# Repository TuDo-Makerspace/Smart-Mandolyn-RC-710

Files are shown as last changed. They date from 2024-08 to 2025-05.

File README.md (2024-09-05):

# Hacking a Mandolyn RC-710 RF Remote Power Socket <!-- omit in toc -->

<p align="center">
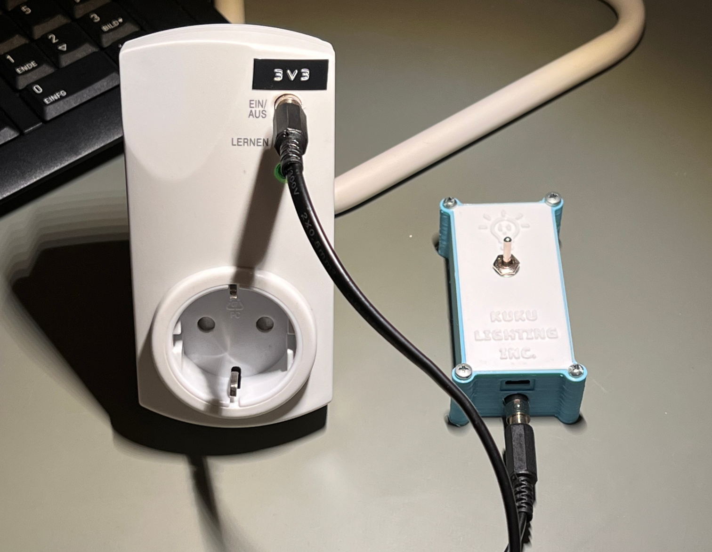
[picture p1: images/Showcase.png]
Showcase
  
</p>

In this project, I hacked a budget-friendly Mandolyn RC-710 RF remote power socket to make it controllable via WiFi—in other words, to turn it into a "smart" power socket. Along the way, I reverse-engineered the RC-710's schematics, modified the PCB to safely allow external toggling of the built-in relay, and developed an ESP8266-based board that controls the relay wirelessly via TCP.

## Table of Contents <!-- omit in toc -->

- [Disclaimer](#disclaimer)
- [Motivation](#motivation)
  - [1. The primary motivation: Laziness](#1-the-primary-motivation-laziness)
  - [2. Why Not Just Buy a WiFi Smart Plug?](#2-why-not-just-buy-a-wifi-smart-plug)
  - [3. Why not build something from scratch?](#3-why-not-build-something-from-scratch)
  - [4. Why the Mandolyn RC-710?](#4-why-the-mandolyn-rc-710)
- [About the Mandolyn RC-710](#about-the-mandolyn-rc-710)
    - [The power socket](#the-power-socket)
    - [The remote](#the-remote)
    - [Availability](#availability)
- [Reverse Engineering the RC-710](#reverse-engineering-the-rc-710)
  - [Opening the RC-710](#opening-the-rc-710)
  - [Reverse Engineering the Schematic](#reverse-engineering-the-schematic)
  - [The circuit](#the-circuit)
    - [Power Supply](#power-supply)
    - [Relay](#relay)
    - [RF Receiver](#rf-receiver)
    - [The blob IC](#the-blob-ic)
- [Modifying the RC-710](#modifying-the-rc-710)
  - [Safety First](#safety-first)
  - [Hijacking the PCB](#hijacking-the-pcb)
- [WiFi Board](#wifi-board)
  - [Design](#design)
  - [Firmware](#firmware)
- [Mobile App](#mobile-app)
- [Conclusion](#conclusion)

## Disclaimer

<p align="center">
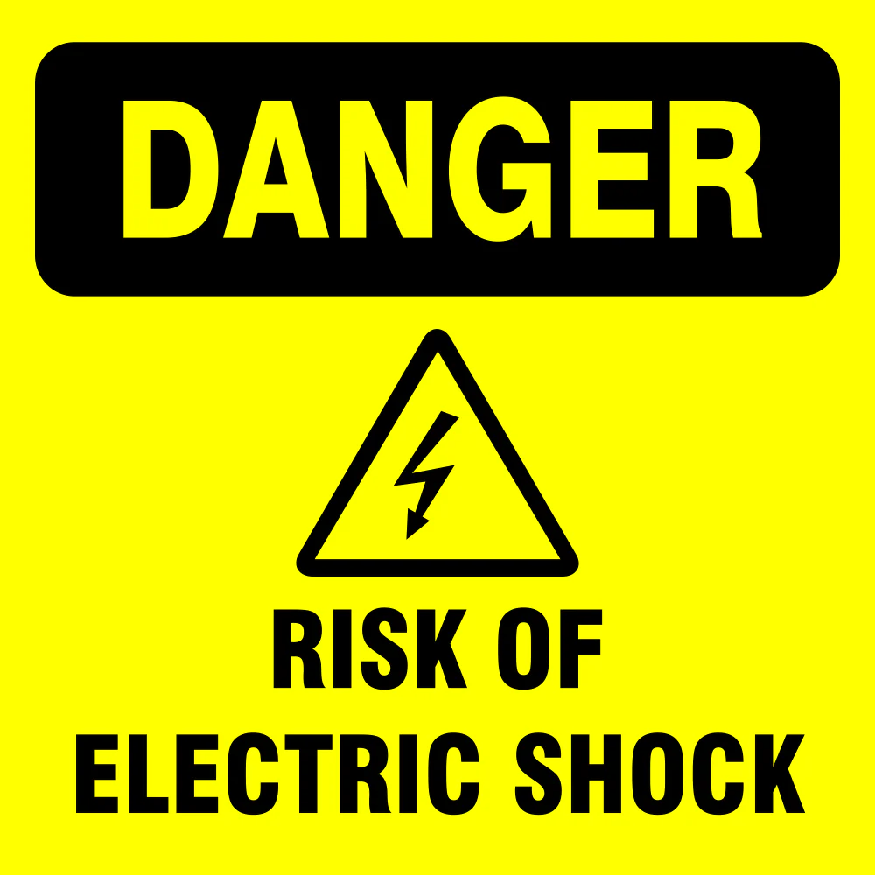
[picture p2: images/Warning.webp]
Warning
  
</p>

The RC-710 is powered by an unisolated power supply. This means that when the device is powered from mains as intended, any low voltages measured on the board will still be at a potentially lethal voltage relative to earth ground. To stress this: Simply touching a pin labeled "0V GND" on the schematic will apply a dangerous voltage (at worst 325V DC) across your body! As we’ll explore, a 24V DC power supply can be connected to the board instead of mains for testing purposes, eliminating the risk of electric shock. However, it should be crystal clear: **Do not mess with this device unless you know exactly what you’re doing! I am not responsible for any damage or injury caused by attempting to replicate this project.** Even with my experience, I am still endangering myself by working on this device.

## Motivation

### 1. The primary motivation: Laziness

We have a 230V powered IKEA lamp in our apartment. Sometimes, I’m just too lazy to get up and turn it off… Seriously, that’s the whole reason.

### 2. Why Not Just Buy a WiFi Smart Plug?

I could’ve bought a 10€ WiFi "smart plug," but I’m not thrilled with what’s out there. For one, I still like having a physical button or switch within easy reach to control the lamp. Most smart plugs I found only have a button directly on the plug. This can lead to awkward situations where you try to use the lamp’s built-in switch, but it doesn’t turn on because the smart plug is off. Having a separate, easily reachable button should avoid this issue.

The second reason is that I’m not a fan of the apps that come with these plugs. They often offer way more than I need. As you’ll see later, I’ve built my own app for this project that just shows a tappable photo of the lamp to toggle it on and off. Simple, straightforward, and tailored to my needs. Some might even call it an enterprise solution :)

### 3. Why not build something from scratch?

Hacking an existing remote power socket offers the advantage of a ready-made enclosure and a PCB that’s (hopefully) designed to handle the high voltages safely.

### 4. Why the Mandolyn RC-710?

We had a few of these lying around the lab, collecting dust. I figured it was time to give them a new purpose.

## About the Mandolyn RC-710

The RC-710 is a remote-controlled power socket that toggles on and off using a 433MHz RF remote, which comes bundled with the socket.

#### The power socket

The socket itself has two buttons: one to manually toggle the power on and off, and another to "learn" a new remote code. It also has a green LED that lights up when the socket is on.

<p align="center">
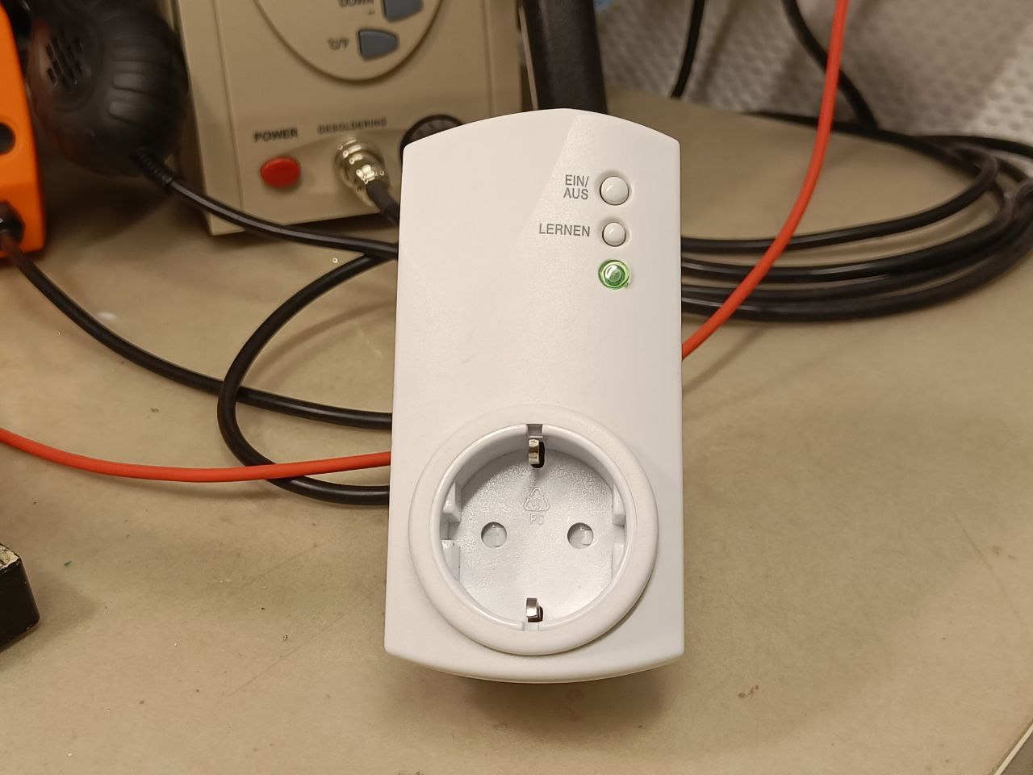
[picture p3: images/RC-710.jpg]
RC-710
  
</p>

#### The remote

The RF remote operates on up to four channels, each with its own unique 433MHz code. Each channel has an ON and an OFF button, allowing you to control multiple sockets independently. It also features two "Xanax-shaped" buttons: one to toggle all channels on or off simultaneously, and another to dim or brighten the connected device. The dimming function is not supported by the RC-710 and is intended for another model.

Since this project discards the RF remote in favor of WiFi control, we won’t be delving into the remote any further.

<p align="center">
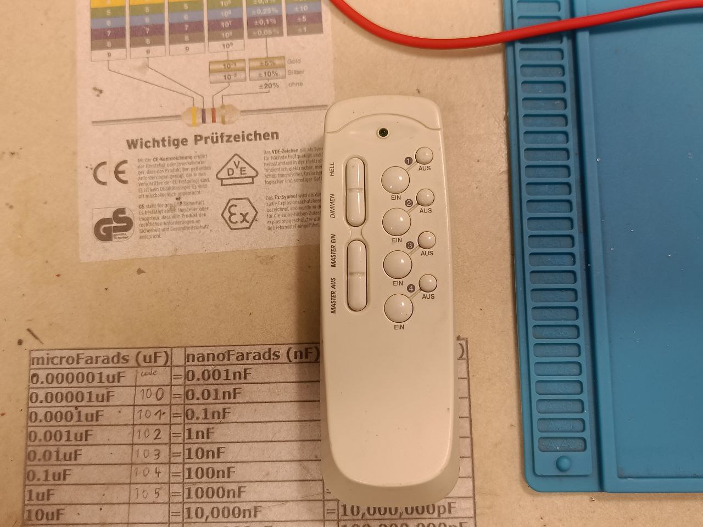
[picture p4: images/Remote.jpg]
Remote
  
</p>

#### Availability

Not much information is available about these things. They’re sold under various brand names (e.g., Voltcraft Cost Control 3000), but the internals remain the same. I also believe they were once sold at Lidl.

## Reverse Engineering the RC-710

### Opening the RC-710

Opening up the RC-710 is pretty straightforward. Start by removing the six screws on the back, and the two halves of the enclosure will come apart easily. You might also need to press in the AC plug to release it from the enclosure.

<p align="center">
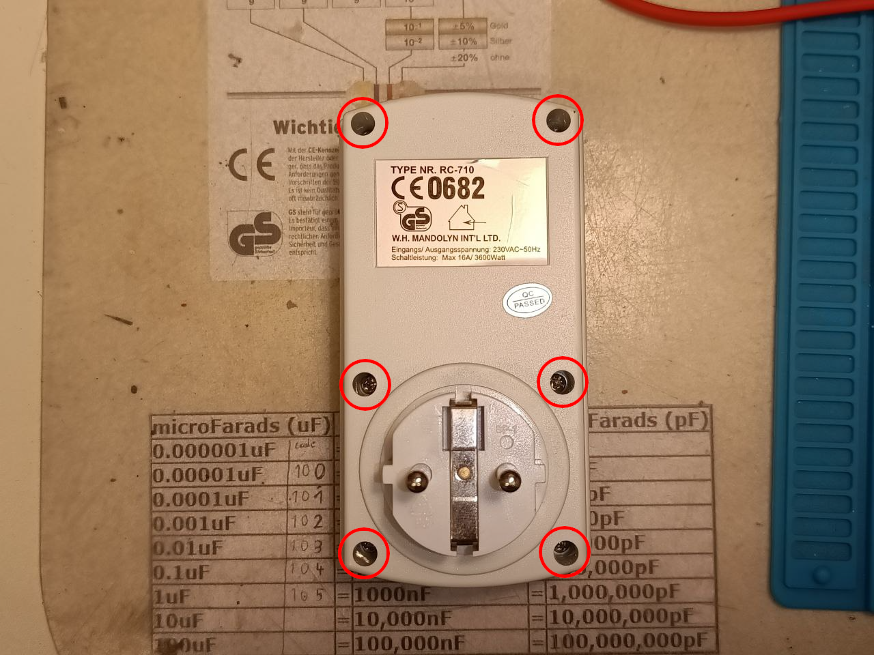
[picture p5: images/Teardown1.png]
Screws Outside
  
</p>

Once inside, you'll see the top side of a simple one-sided PCB. The PCB is secured with four smaller screws. After removing these, you can lift the PCB out of the enclosure.

<p align="center">
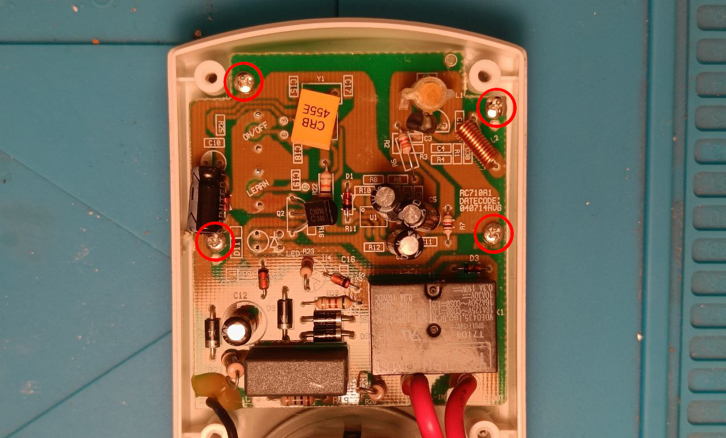
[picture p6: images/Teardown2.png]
Screws PCB
  
</p>

### Reverse Engineering the Schematic

I started by taking photos of both the top and bottom sides of the PCB, then overlapping them in GIMP. After adjusting the images, I managed to get the traces of both layers almost perfectly aligned. This setup allowed me to quickly toggle between the two layers by simply showing or hiding the top layer.

<p align="center">
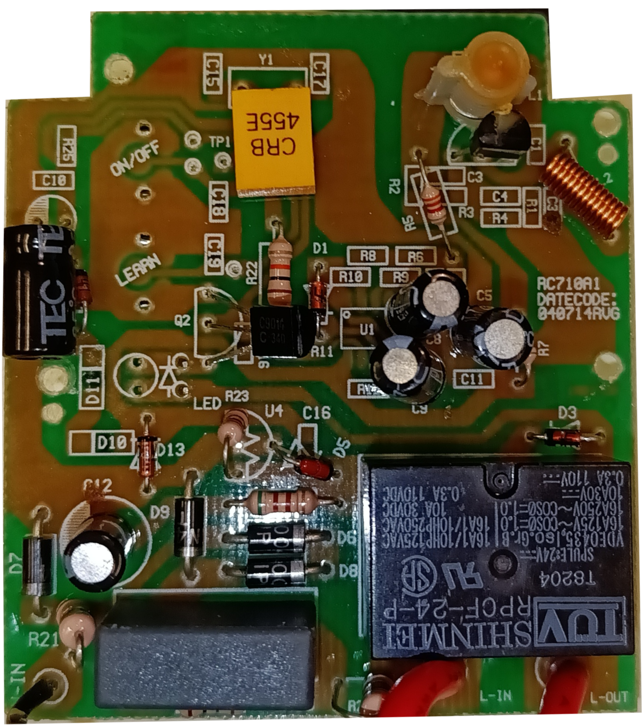
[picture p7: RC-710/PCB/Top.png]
PCB Top
  
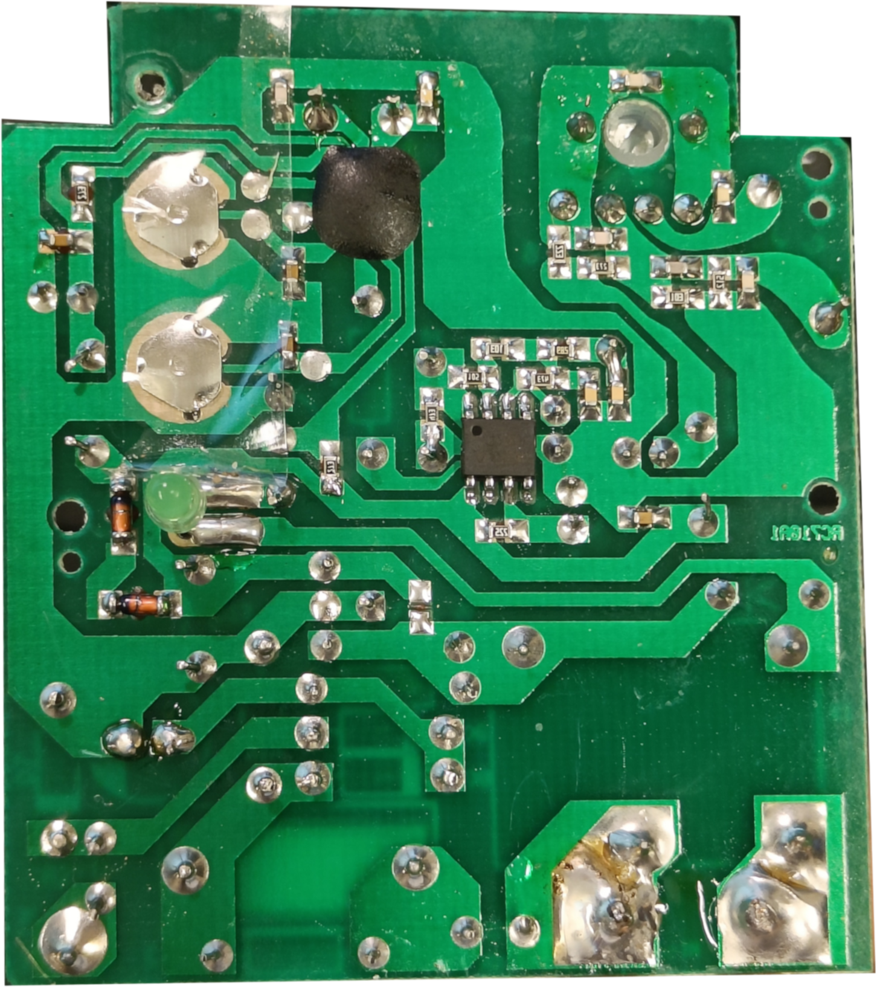
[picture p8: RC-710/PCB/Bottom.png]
PCB Bottom
  
</p>

On a second screen, I opened up KiCAD to create a schematic. I began by adding symbols for all the components. From there, I started connecting the symbols according to the PCB's traces. When the images from GIMP didn’t provide enough detail, I used a multimeter to verify connections between components. After getting everything laid out, I was left with a rather messy schematic. The final step was to clean it up and make it more readable.

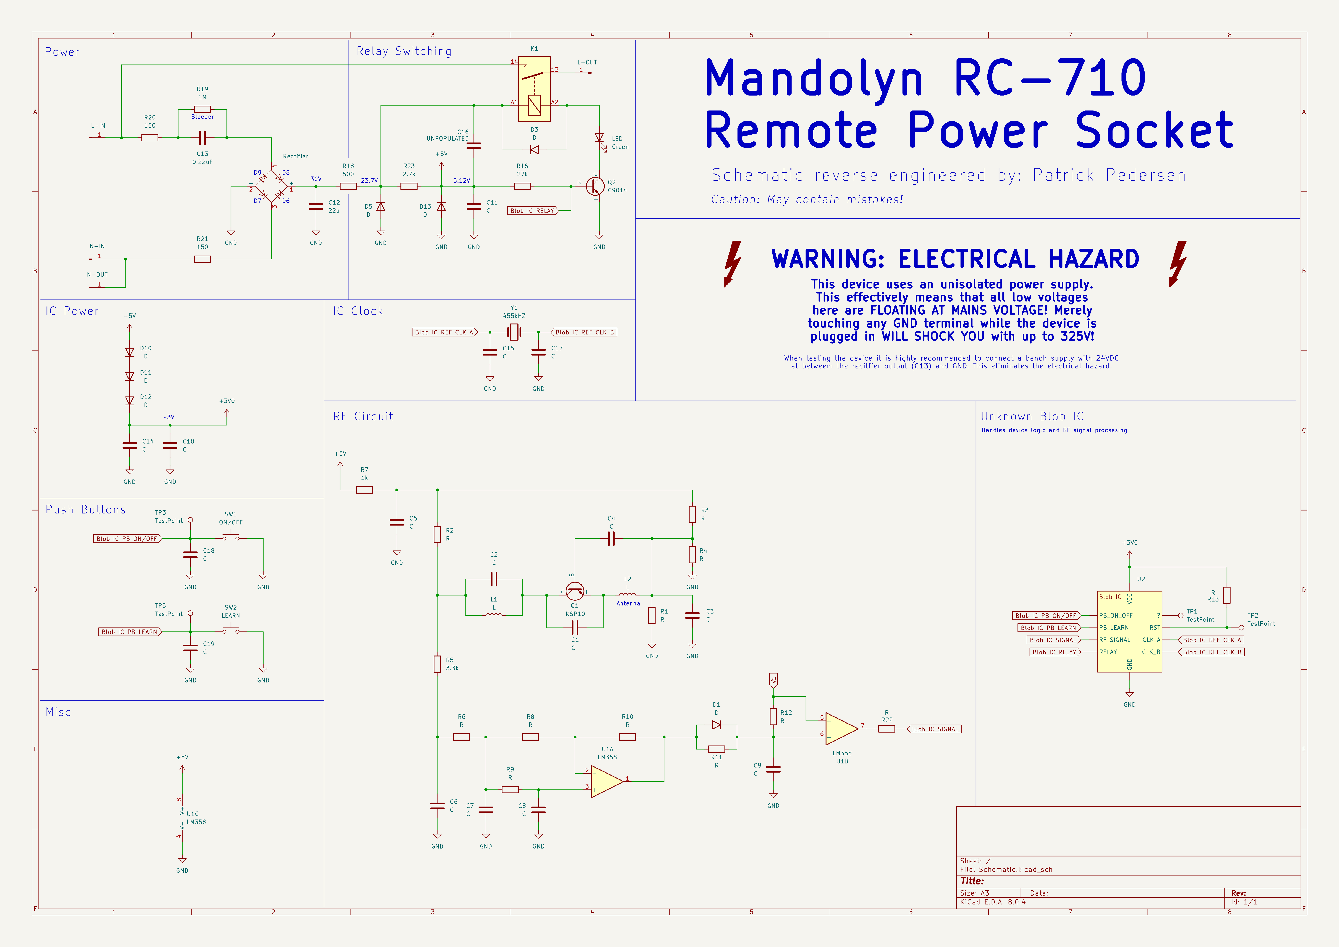
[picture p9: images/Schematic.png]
Schematic


### The circuit

All-in-all, the circuit can be summarized into 3 main parts: the power supply, the relay, and the RF receiver. Most of the device's functionality is handled by a mysterious blob IC.

#### Power Supply

The power supply circuit is as simple as it gets. The AC mains voltage is first rectified by a full-wave bridge rectifier. This rectified voltage is then regulated down to 24V DC using a Zener diode and a smoothing capacitor. The 24V DC is used to power the relay. Finally, the 24V DC is further regulated down to 5V DC, again using a Zener diode and a smoothing capacitor, to supply power to the rest of the circuitry.

<p align="center">
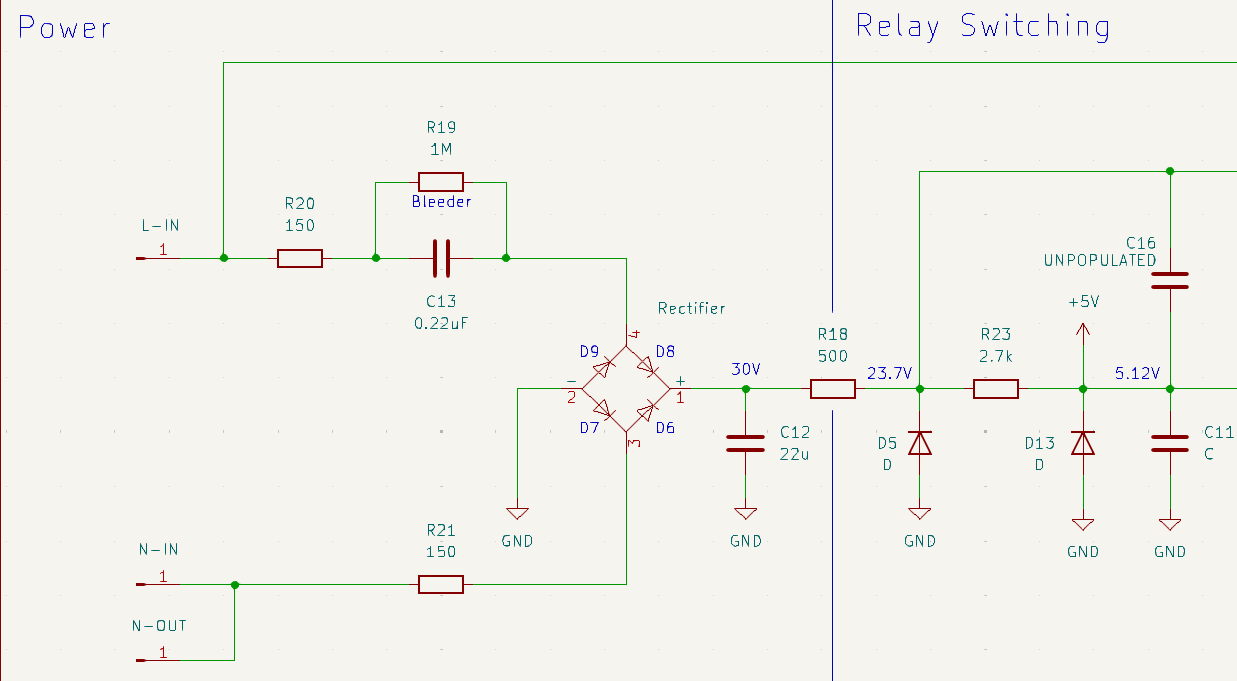
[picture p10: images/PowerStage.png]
Power Supply
  
</p>

#### Relay

The relay's job is to switch the "live" line. To activate the relay, transistor Q2 is employed. Applying a 5V signal to the base of transistor Q2 activates it, allowing current to flow through the relay coil and closing the relay circuit. This also turns on the indicator LED, as it is connected in series with the relay coil. When the relay is activated, it closes the "live" line.

The mysterious blob IC is responsible for controlling the relay by either pulling the transistor's base low or leaving it floating at 5V. When the device powers up, the IC's pin defaults to a floating state, meaning the relay circuit is closed and the device is enabled.

<p align="center">
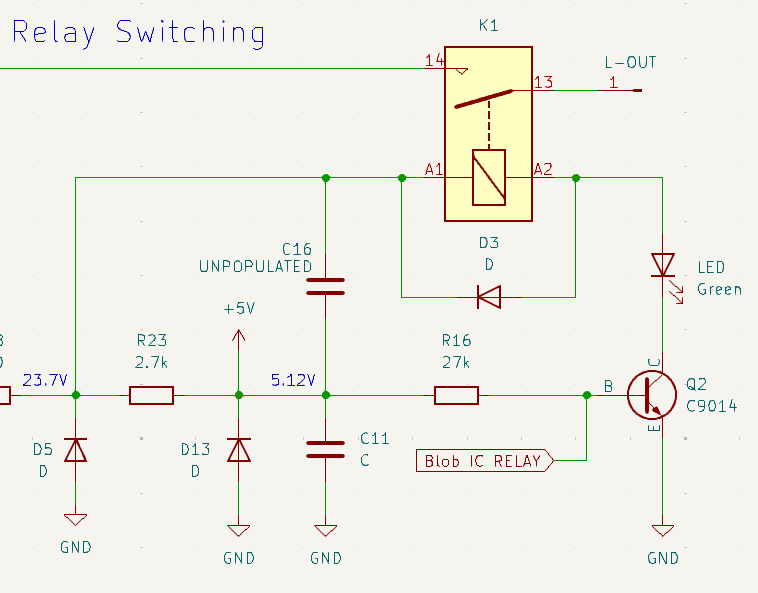
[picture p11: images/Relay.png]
Relay
  
</p>

#### RF Receiver

The RF receiver is made up of a network of capacitors, inductors, and transistors. I haven’t delved too deeply into this section of the circuit, as it’s quite complex and not directly relevant to my objective. From what I can gather, the RF signal is amplified and then converted into a PWM signal by the LM358 Op-Amp (U1). It seems that the actual demodulation and decoding of the signal is entirely handled by the mysterious blob IC.

<p align="center">
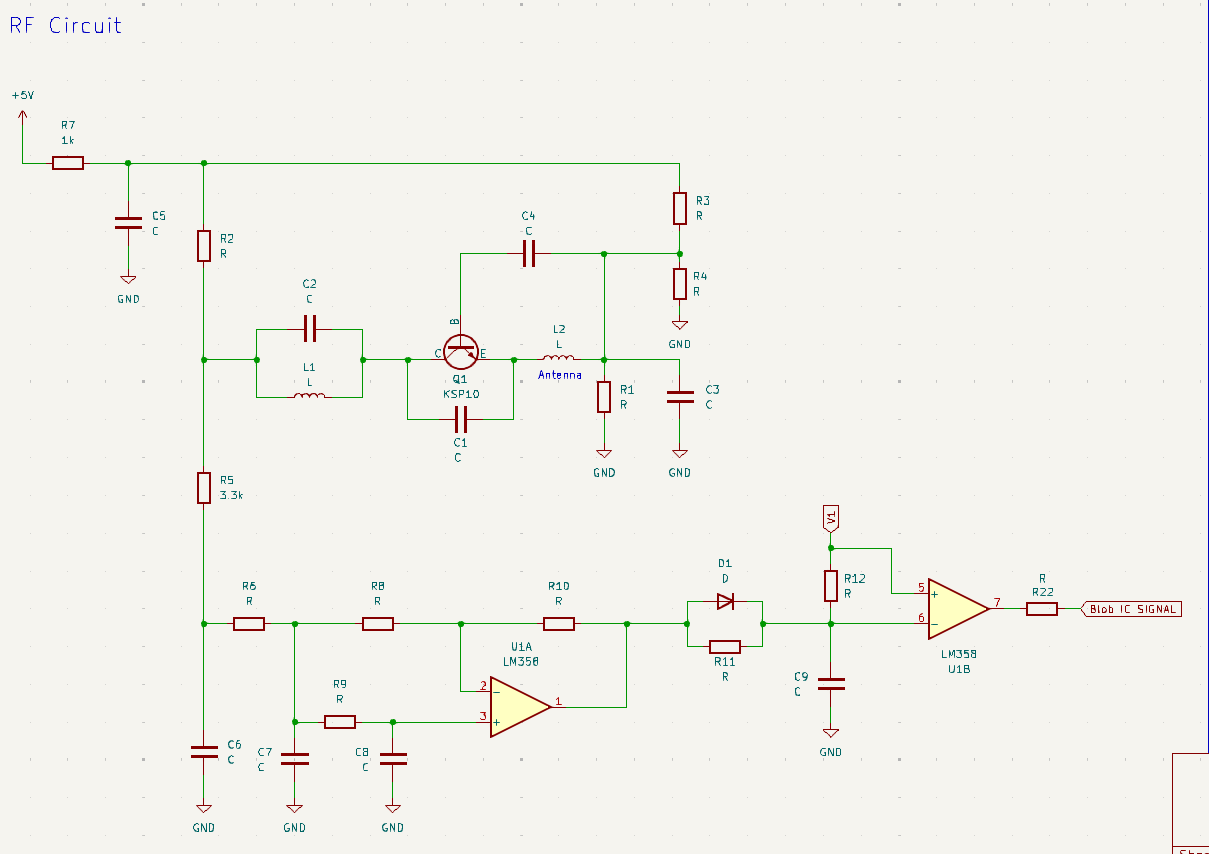
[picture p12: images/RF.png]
RF Receiver
  
</p>

#### The blob IC

The mysterious blob IC serves as the brains of the device. It is powered by approx. 3V (regulated down from the 5V supply using diodes) and manages the "LEARN" and "ON/OFF" push-buttons, decodes and "learns" RF signals, and ultimately controls the relay by switching the transistor Q2.

<p align="center">
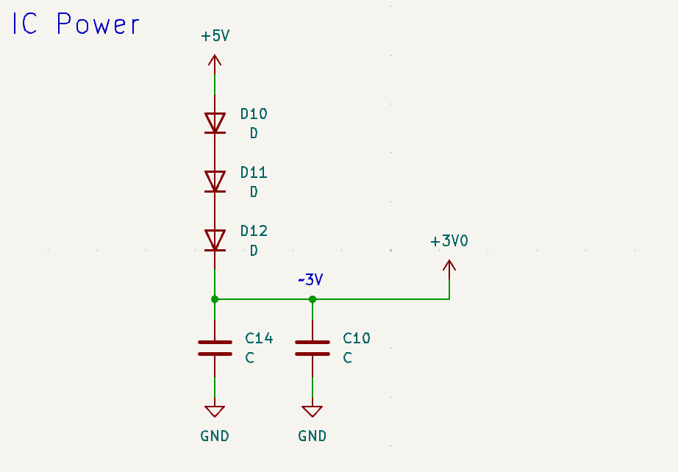
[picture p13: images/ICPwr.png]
Blob IC Power
  
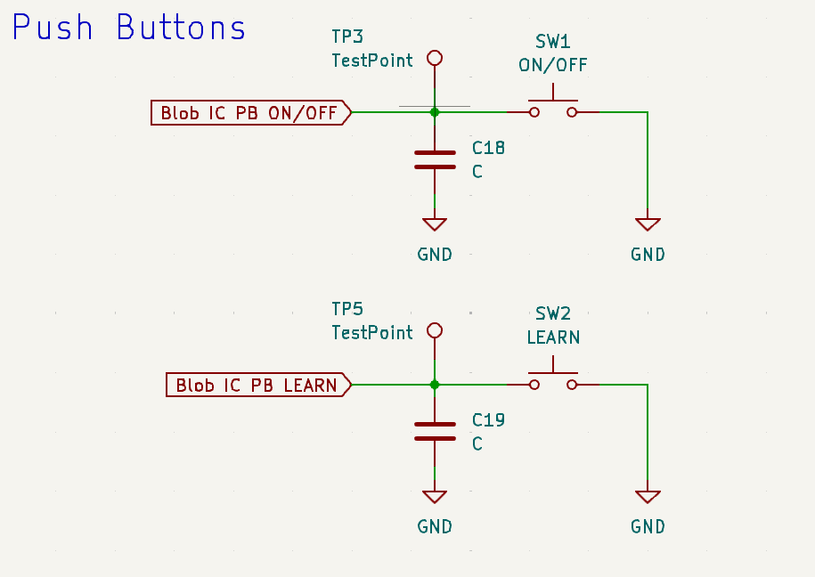
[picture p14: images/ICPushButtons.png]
Blob IC Push Buttons
  
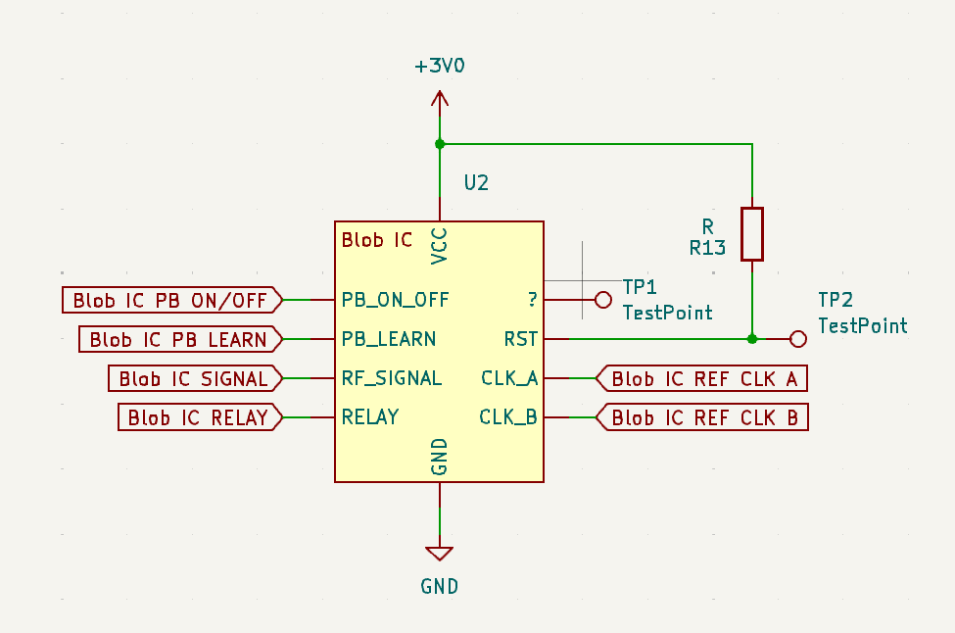
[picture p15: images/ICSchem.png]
Blob IC Schematic
  
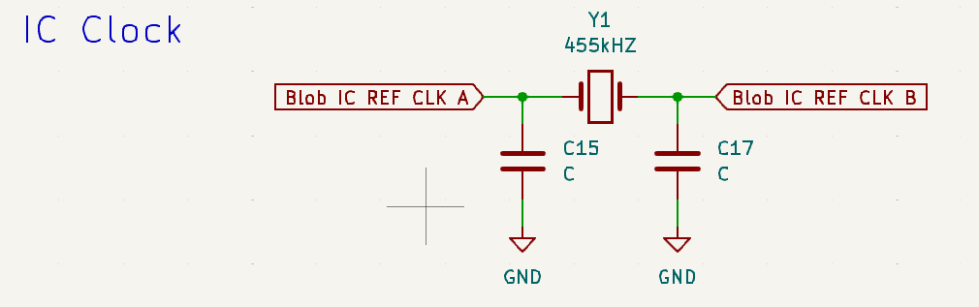
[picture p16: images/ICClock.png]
Blob IC Clock
  
</p>

<p align="center">
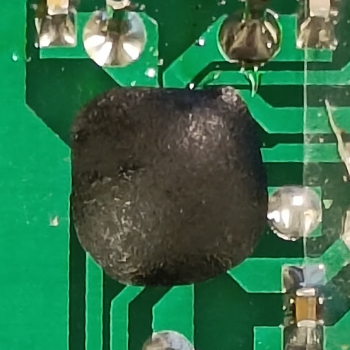
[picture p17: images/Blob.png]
Blob IC
  
</p>

## Modifying the RC-710

### Safety First

Before applying any modifications to the RC-710, I wanted to ensure that I could safely work on the device without the risk of electric shock.To achieve this, I decided to power the device using a 24V DC power supply instead of mains by attaching the postive lead to the positive side of C12 and the negative lead to GND.

<p align="center">
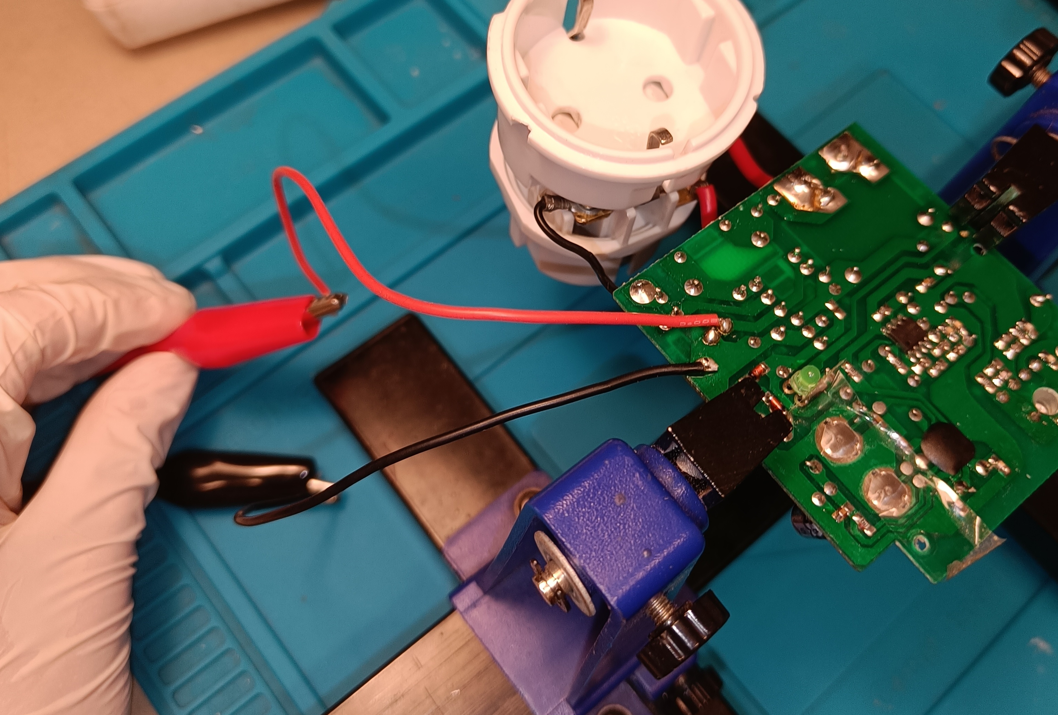
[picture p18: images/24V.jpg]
24V DC Power Supply
  
</p>

A 5V supply can theoretically also be used to power the device, but the relay will no longer be able to switch due to the insufficiently strong magnetic field.

### Hijacking the PCB

I set some straightforward rules and requirements for the project:

- The relay should be controllable via an external signal:
  - An ON signal should close the relay.
  - An OFF signal should open the relay.
- The state of the relay must be predictable:
  - The device's internal functions should not interfere with the external signal.
- The device's internal functionality does not need to be preserved.
- The external signal must be electrically isolated from the device.

To hijack the device, the first step was to find a simple way to disable the blob IC. That way I didn't have to worry about the device's internal functions interfering with the external signal. This was easily achieved by depraiving the blob IC of its power by desoldering diode D12. Later I discovered that R22 also needed to be removed, as a high state on the OP-AMP’s output was feeding blob with power to pull down the base of the relay driver transistor Q2.

<p align="center">
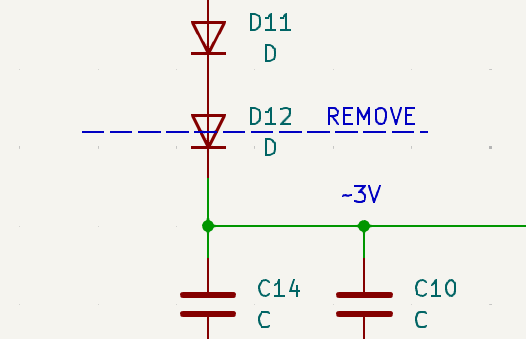
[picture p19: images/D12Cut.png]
D12 Removed
  
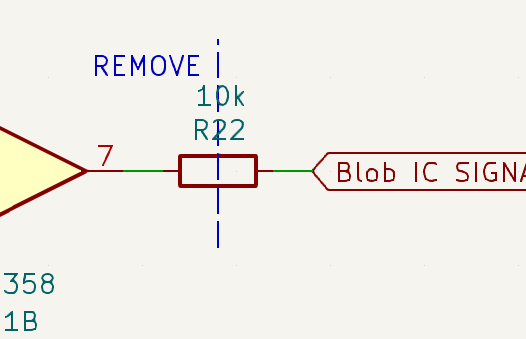
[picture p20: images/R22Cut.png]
R22 Removed
  
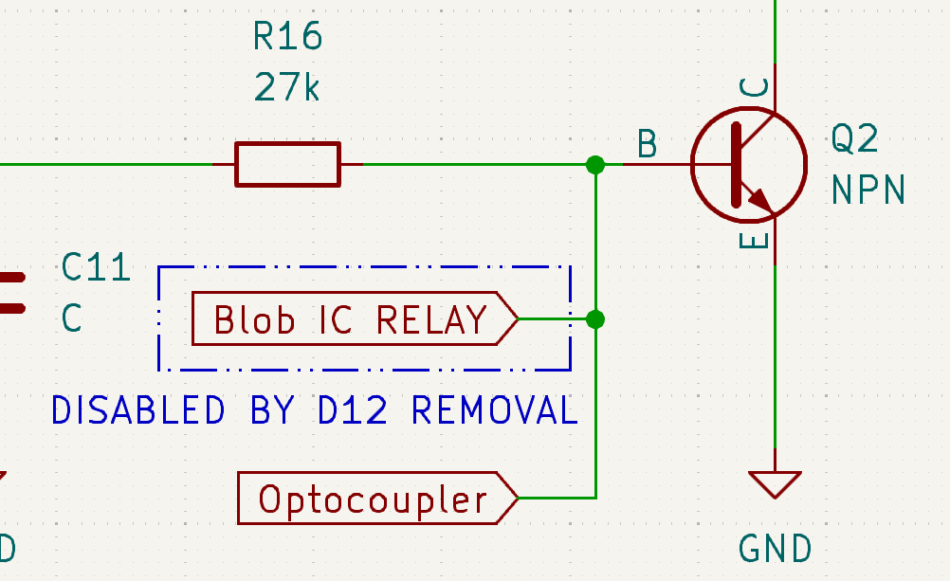
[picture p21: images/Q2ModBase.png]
Blob IC Disabled
  
</p>

The next step was to enable external control of the relay transistor's base. I wanted to add a 2-pin connector to the device's case that could be used to control the relay. For safety, this connector needed to be electrically isolated from the rest of the device. To achieve this, I used a 4N25 optocoupler, which we had plenty of in the lab, and a 3.5mm headphone jack as the external connector.

The 4N25 optocoupler contains an NPN phototransistor. By connecting the phototransistor to the base of Q2, the base would be pulled down when the phototransistor is activated (disabling the relay) and left floating when it's off (enabling the relay). I chose a headphone jack as the connector because it’s a widely available standard, and long audio cables are inexpensive or easy to make.

To protect the "low voltage" side of the optocoupler, I also added a 220 Ohm current-limiting resistor. While the use of a headphone jack might tempt someone to connect an audio source to it, the high output impedance of audio devices, combined with the 220 Ohm resistor, should keep the optocoupler safe. In the worst-case scenario, it would just cause the relay to toggle rapidly.

<p align="center">
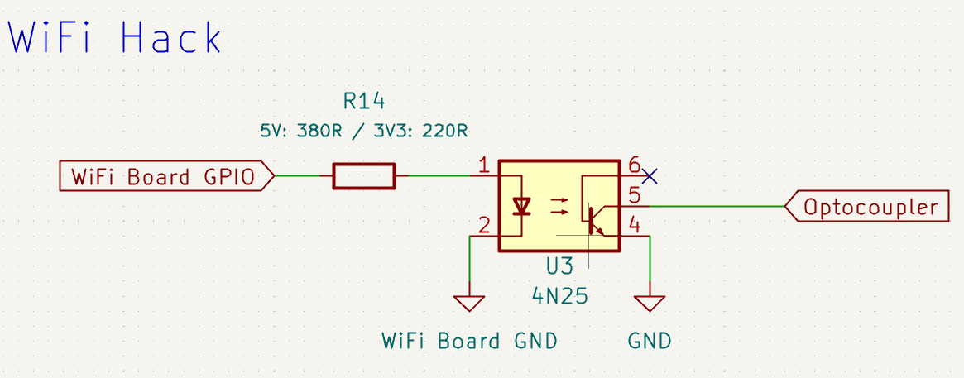
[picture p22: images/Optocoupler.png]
Optocoupler
 
</p>

After soldering the optocoupler to the PCB and the headphone jack, I secured the optocoupler inside the case with glue. The headphone jack was glued into the hole previously used for the "ON/OFF" push-button. I also used a JST XH 2-pin connector between the optocoupler and the PCB for the "hot" connection. This allows the PCB to still be easily removed from the case. For added safety, I applied plenty of electrical tape to any areas that could potentially expose the exterior to the device's mains voltage, even remotely.

<p align="center">
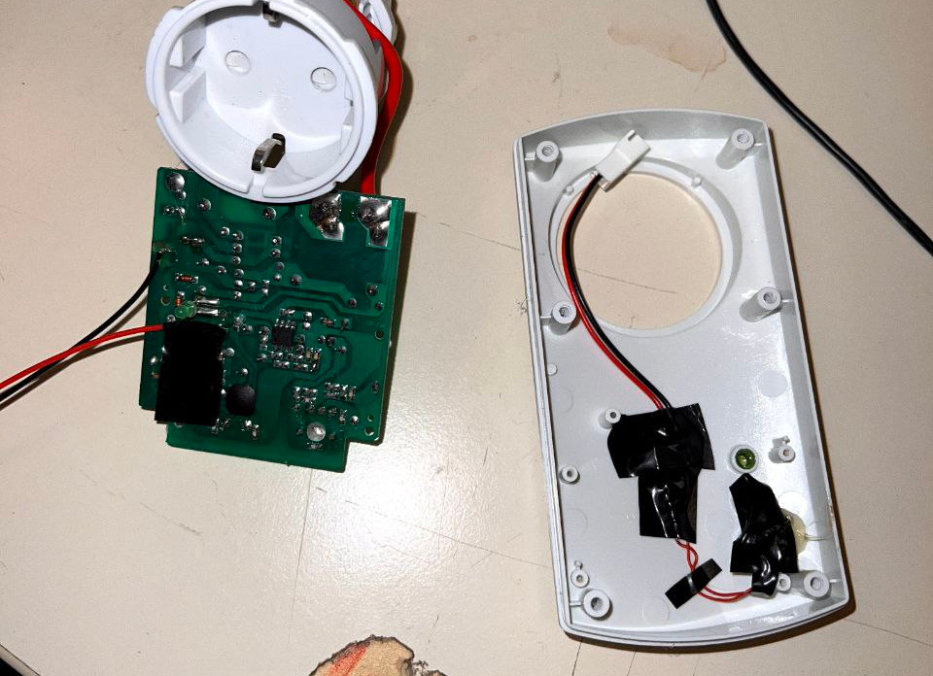
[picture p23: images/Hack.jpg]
Inside
  
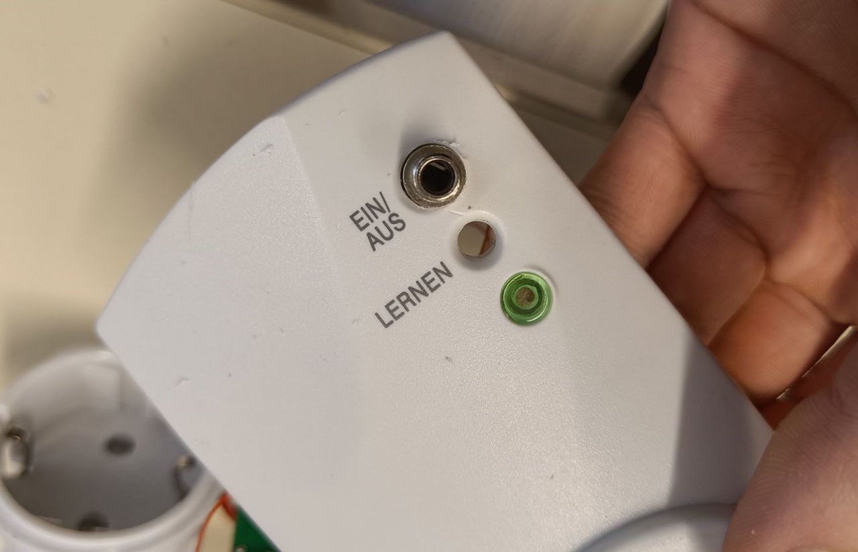
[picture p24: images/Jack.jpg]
Jack
  
</p>

Now the device was ready to be controlled externally. The next step was to design a board that could control the relay wirelessly via WiFi.

## WiFi Board

### Design

For the WiFi module, I used a D1 Mini ESP8266 board, along with a switch and a 3.5mm headphone jack. The switch allows manual toggling of the relay, while the headphone jack connects the board to the RC-710. Everything was soldered onto a perfboard and housed in a 3D-printed case. To power the board, the micro USB port on the D1 Mini is used.

<p align="center">
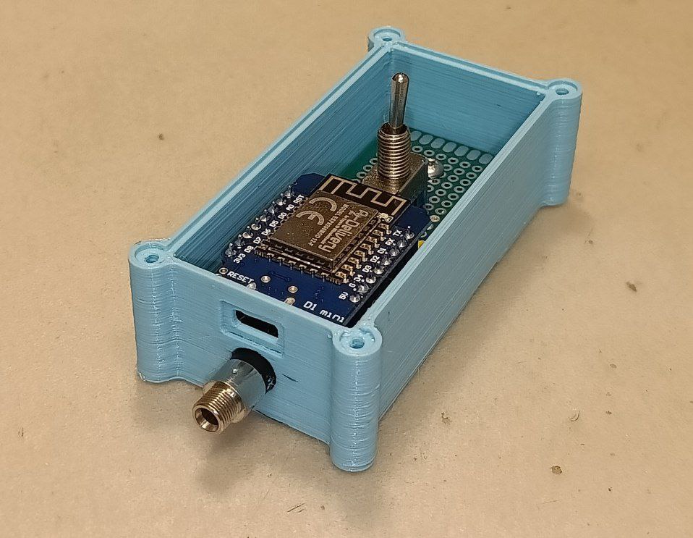
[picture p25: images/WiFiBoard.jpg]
WiFi Board
  
</p>

### Firmware

The firmware for the ESP8266 is designed to be adaptable for various projects. In essence, the firmware simply converts TCP packets into GPIO signals.
It can be configured through the [config.h](firmware_wifiboard/src/config.h) file where you can adjust settings such as WiFi credentials, pin assignments, the type of physical input (switch, pushbutton, or none), action modes (ON/OFF, toggle, or pulse), and more.

As a small side note: I also used this firmware for another project where I control a USB-powered IKEA lamp via a transistor. In that case, instead of toggling a relay, the firmware controls the lamp's power through a transistor.

The ESP8266 primarily listens for TCP packets that trigger specific actions based on the configured "action mode." In this project, the action mode is set to ON/OFF, where a TCP message of `0x00` turns the relay off, and `0x01` turns it on. The ON/OFF mode also supports a "get" request (`0x03`), which returns the current state of the relay.

Aside from listening for TCP packets, the ESP8266 also mirrors the physical input to the relay. Any changes made to the relay's state through the physical input (e.g., a switch or button) are also updated in the firmware. This ensures that "get" requests always return the correct and current state of the relay.

## Mobile App

The final touch to this project was creating a simple Android mobile app to control the relay, and in my case, the lamp. The app features photos of my wirelessly controllable lamps, and tapping on a lamp's photo toggles it on or off. The app also visually indicates the lamp's state by lighting up the photo when the lamp is on.

<p align="center">
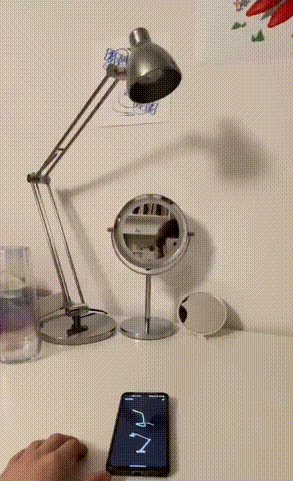
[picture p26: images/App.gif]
App
  
</p>

I won’t be sharing the app’s source code because it’s tailored specifically to my setup and, honestly, it’s a bit messy since this was my first time developing an Android app.

## Conclusion

I am now left with a WiFi-controllable power socket. That's pretty cool I guess.

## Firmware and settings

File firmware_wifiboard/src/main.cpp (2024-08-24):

#include <Arduino.h>
#include <ESP8266WiFi.h>

#include "config.h"

////////////////////////////////////////////
// Meta
////////////////////////////////////////////

#define VERSION "1.0.1_ESP8266"

////////////////////////////////////////////
// Debugging
////////////////////////////////////////////

#if DEBUG > 0
#define DEBUG_PRINTLN(level, x) if (level <= DEBUG) Serial.println(x)
#else
#define DEBUG_PRINTLN(level, x)
#endif

////////////////////////////////////////////
// Actions and States
////////////////////////////////////////////

/**
 * enum device_state
 * Maps device states to their corresponding electrical states
 */

#if MODE == MODE_ON_OFF_INVERTED

enum device_state {
    OFF = HIGH,
    ON = LOW,
};

#else

enum device_state {
    OFF = LOW,
    ON = HIGH,
};

#endif

/**
 * enum action_type
 * Contains the possible actions that can be performed
 * for the selected mode.
 */

#if ANY_MODE_ON_OFF

enum action_type {
    DISABLE,
    ENABLE,
};

#elif MODE == MODE_TOGGLE

enum action_type {
    TOGGLE,
};

#elif MODE == MODE_PULSE_LOW || MODE == MODE_PULSE_HIGH

enum action_type {
    PULSE,
};

#endif

/**
 * Globals
 */

static uint8_t g_state; // Current gpio state of the action pin

/**
 * void init_action_pin()
 * Initializes the action pin as an output and sets it to the boot state.
 * The boot state is defined in config.h.
 */

#if ANY_MODE_ON_OFF || MODE == MODE_TOGGLE

void init_action_pin() {
    pinMode(ACTION_PIN, OUTPUT);
    digitalWrite(ACTION_PIN, BOOT_STATE);
    g_state = BOOT_STATE;
}

#elif MODE == MODE_PULSE_LOW

void init_action_pin() {
    pinMode(ACTION_PIN, OUTPUT);
    digitalWrite(ACTION_PIN, HIGH);
    g_state = HIGH;
}

#elif MODE == MODE_PULSE_HIGH

void init_action_pin() {
    pinMode(ACTION_PIN, OUTPUT);
    digitalWrite(ACTION_PIN, LOW);
    g_state = LOW;
}

#endif

/**
 * void action(action_type action)
 * Performs the action corresponding to the given action type.
 * The action type is determined by the mode defined in config.h.
 */

#if ANY_MODE_ON_OFF

void action(action_type action) {
    switch (action) {
    case DISABLE:
        DEBUG_PRINTLN(1, "Action: Disabling");
        digitalWrite(ACTION_PIN, OFF);
        g_state = OFF;
        break;
    case ENABLE:
        DEBUG_PRINTLN(1, "Action: Enabling");
        digitalWrite(ACTION_PIN, ON);
        g_state = ON;
        break;
    }
}

#elif MODE == MODE_TOGGLE

void action(action_type action) {
    if (action == TOGGLE) {
        DEBUG_PRINTLN(1, "Action: Toggling");
        digitalWrite(ACTION_PIN, !digitalRead(ACTION_PIN));
        g_state = digitalRead(ACTION_PIN);
    }
}

#elif MODE == MODE_PULSE_LOW

void action(action_type action) {
    if (action == PULSE) {
        DEBUG_PRINTLN(1, "Action: Pulsing low");
        digitalWrite(ACTION_PIN, LOW);
        delay(PULSE_TIME);
        digitalWrite(ACTION_PIN, HIGH);
        g_state = HIGH;
    }
}

#elif MODE == MODE_PULSE_HIGH

void action(action_type action) {
    if (action == PULSE) {
        DEBUG_PRINTLN(1, "Action: Pulsing high");
        digitalWrite(ACTION_PIN, HIGH);
        delay(PULSE_TIME);
        digitalWrite(ACTION_PIN, LOW);
        g_state = LOW;
    }
}

#endif

////////////////////////////////////////////
// TCP Requests and Responses
////////////////////////////////////////////

/**
 * uint8_t device_state2tcp(device_state state)
 * Maps a device state to its corresponding tcp data.
 */
#if ANY_MODE_ON_OFF

uint8_t device_state2tcp(device_state state) {
    return state == ON ? TCP_ON_DATA : TCP_OFF_DATA;
}

#elif MODE == MODE_TOGGLE

uint8_t device_state2tcp(device_state state) {
    return TCP_TOGGLE_DATA;
}

#elif MODE == MODE_PULSE_LOW || MODE == MODE_PULSE_HIGH

uint8_t device_state2tcp(device_state state) {
    return TCP_PULSE_DATA;
}

#endif

/**
 * int tcp2action_type(uint8_t data, action_type *type)
 * Maps a tcp data to its corresponding action type.
 * If data can't be mapped to an action type, -1 is returned.
 */

#if ANY_MODE_ON_OFF

int tcp2action_type(uint8_t data, action_type *type) {
    switch (data) {
    case TCP_OFF_DATA:
        *type = DISABLE;
        return 0;
    case TCP_ON_DATA:
        *type = ENABLE;
        return 0;
    default:
        return -1;
    }
}

#elif MODE == MODE_TOGGLE

int tcp2action_type(uint8_t data, action_type *type) {
    if (data == TCP_TOGGLE_DATA) {
        *type = TOGGLE;
        return 0;
    }

    return -1;
}

#elif MODE == MODE_PULSE_LOW || MODE == MODE_PULSE_HIGH

int tcp2action_type(uint8_t data, action_type *type) {
    if (data == TCP_PULSE_DATA) {
        *type = PULSE;
        return 0;
    }

    return -1;
}

#endif

/**
 * bool answer(WiFiClient *c, uint8_t get_request)
 * Answers the client based on the get_request.
 * If get_request is not recognized (i.e. its a set_request), false is returned.
 */
#if ANY_MODE_ON_OFF

bool answer(WiFiClient *c, uint8_t get_request) {
    if (get_request == TCP_GET_STATE) {
        DEBUG_PRINTLN(2, "get_request: TCP_GET_STATE");
        c->write(device_state2tcp(device_state(g_state)));
        return true;
    }
    return false;
}


#else

bool answer(WiFiClient *c, uint8_t get_request) {
    return false;
}

#endif

////////////////////////////////////////////
// Physical Inputs
////////////////////////////////////////////

/**
 * void init_physical_input()
 * Initializes the physical input pin as an input with pullup.
 * If no physical input is defined, this function does nothing.
 */

#if PHYSICAL_INPUT == PHYS_BUTTON || PHYSICAL_INPUT == PHYS_SWITCH

void init_physical_input() {
    pinMode(PHYSICAL_PIN, INPUT_PULLUP);
}

#else

void init_physical_input() {}

#endif

/**
 * bool eval_physical_input()
 * Returns true if the physical input has changed state.
 * - In case of a button this means the button has been pressed.
 * - In case of a switch this means the switch has been toggled.
 * If no physical input is defined, always returns false.
 */
#if PHYSICAL_INPUT == PHYS_BUTTON

bool eval_physical_input() {
    static bool last_state = digitalRead(PHYSICAL_PIN);
    bool current_state = digitalRead(PHYSICAL_PIN);

    bool pressed = last_state && !current_state;
    last_state = current_state;

    if (pressed) {
        delay(DEBOUNCE_TIME);

        uint32_t wrong = 0;
        for (int i = 0; i < SAMPLES; i++) {
            if (digitalRead(PHYSICAL_PIN) != current_state)
                wrong++;
        }

        return wrong < (SAMPLES / 2);
    }

    return false;
}

#elif PHYSICAL_INPUT == PHYS_SWITCH

bool eval_physical_input() {
    static bool last_state = digitalRead(PHYSICAL_PIN);
    bool current_state = digitalRead(PHYSICAL_PIN);

    bool toggled = last_state != current_state;
    last_state = current_state;

    return toggled;
}
#else
bool eval_physical_input() {
    return false;
}

#endif

/**
 * void action_on_phys()
 * Executes the appropriate action on physical input.
 */

#ifdef ANY_MODE_ON_OFF

void action_on_phys() {
    action(g_state == ON ? DISABLE : ENABLE);
}

#elif MODE == MODE_TOGGLE

void action_on_phys() {
    action(TOGGLE);
}

#elif MODE == MODE_PULSE_LOW || MODE == MODE_PULSE_HIGH

void action_on_phys() {
    action(PULSE);
}

#endif


////////////////////////////////////////////
// WiFi
////////////////////////////////////////////

/**
 * void config_wifi()
 * Configures static IP, gateway and subnet if USE_STATIC_IP is defined.
 * Else, this function does nothing.
 */
#ifdef USE_STATIC_IP

void config_wifi() {
    IPAddress ip, gateway, subnet;
    ip.fromString(STATIC_IP);
    gateway.fromString(GATEWAY);
    subnet.fromString(SUBNET);

    WiFi.config(ip, gateway, subnet);

    DEBUG_PRINTLN(2, "\nConfigured WiFi with: ");
    DEBUG_PRINTLN(2, "IP: " STATIC_IP);
    DEBUG_PRINTLN(2, "Gateway: " GATEWAY);
    DEBUG_PRINTLN(2, "Subnet: " SUBNET "\n");
}

#else

void config_wifi() {}

#endif

////////////////////////////////////////////
// Timeouts
////////////////////////////////////////////

static unsigned long tstamp;

void set_timeout(unsigned long timeout) {
    tstamp = millis() + timeout;
}

bool timeout() {
    return millis() > tstamp;
}

////////////////////////////////////////////
// Misc
////////////////////////////////////////////

#define BUILTIN_LED_OFF HIGH
#define BUILTIN_LED_ON LOW

////////////////////////////////////////////
// Main
////////////////////////////////////////////

WiFiServer server(TCP_PORT);

void setup() {
    init_physical_input();
    init_action_pin();

#ifdef DEBUG
    Serial.begin(115200);
    delay(1000);
#endif

    DEBUG_PRINTLN(1, "====== TCP Action Server " VERSION "======");

    config_wifi();

    WiFi.setAutoReconnect(true);
    WiFi.persistent(true);

    pinMode(LED_BUILTIN, OUTPUT);
    bool led_state = BUILTIN_LED_OFF;

    // Connect to Wi-Fi
    DEBUG_PRINTLN(1, "Connecting to " WIFI_SSID "...");
    WiFi.begin(WIFI_SSID, WIFI_PSK);

    while (WiFi.status() != WL_CONNECTED) {
        if (eval_physical_input()) {
            DEBUG_PRINTLN(1, "Physical input detected");
            action_on_phys();
        }

        digitalWrite(LED_BUILTIN, led_state = !led_state);
        delay(250);
    }

    digitalWrite(LED_BUILTIN, led_state = BUILTIN_LED_OFF);
    pinMode(LED_BUILTIN, INPUT);

    DEBUG_PRINTLN(1, "Connected to " WIFI_SSID);

    server.begin();

    DEBUG_PRINTLN(1, "Started TCP server");
}

void loop() {
    // Handle physical input
    if (eval_physical_input()) {
        DEBUG_PRINTLN(1, "Physical input detected");
        action_on_phys();
    }

    // Handle TCP requests
    WiFiClient client = server.accept();
    if (client) {
        DEBUG_PRINTLN(2, "Client connected");
        set_timeout(CLIENT_TIMEOUT);

        while (client.connected() && !timeout()) {
            if (!client.available()) {
                DEBUG_PRINTLN(3, "Awaiting data...");
                continue;
            }

            uint8_t data = client.read();

            if (answer(&client, data)) {
                set_timeout(CLIENT_TIMEOUT);
                continue;
            }

            action_type a;

            if (tcp2action_type(data, &a) == 0)
                action(a);

            set_timeout(CLIENT_TIMEOUT);
        }

        if (timeout()) {
            DEBUG_PRINTLN(1, "Client timed out");
        } else {
            DEBUG_PRINTLN(2, "Client disconnected");
        }

        client.stop();
    }
}

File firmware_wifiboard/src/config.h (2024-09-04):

#pragma once

/*
 * Copyright (C) 2024 Patrick Pedersen

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
 */

#include "config_enums.h"

#define ANY_MODE_ON_OFF (MODE == MODE_ON_OFF || MODE == MODE_ON_OFF_INVERTED)

////////////////////////////////////////////
// Debug Configuration
////////////////////////////////////////////

#define DEBUG 0

////////////////////////////////////////////
// WiFi configuration
////////////////////////////////////////////

#define WIFI_SSID "YOUR SSID"
#define WIFI_PSK "YOUR PSK"
#define TCP_PORT 8080
#define CLIENT_TIMEOUT 30 * 1000 // ms

#define USE_STATIC_IP // Comment out for DHCP

// Only needs to be set if USE_STATIC_IP defined
#ifdef USE_STATIC_IP
#define STATIC_IP "192.168.1.10"
#define GATEWAY "192.168.1.1"
#define SUBNET "255.255.255.0"
#endif

////////////////////////////////////////////
// Push Button/Switch Configuration
////////////////////////////////////////////

#define PHYSICAL_INPUT PHYS_SWITCH // PHYS_BUTTON, PHYS_SWITCH or comment out if not used
#define PHYSICAL_PIN 4

#if PHYSICAL_INPUT == PHYS_BUTTON
#define DEBOUNCE_TIME 20 // ms
#define SAMPLES 10
#endif

////////////////////////////////////////////
// Action Configuration
////////////////////////////////////////////

#define ACTION_PIN 5

/**
 * Possible values:
 *  - MODE_ON_OFF
 *  - MODE_ON_OFF_INVERTED
 *  - MODE_TOGGLE
 *  - MODE_PULSE_LOW
 *  - MODE_PULSE_HIGH
 */
#define MODE MODE_ON_OFF_INVERTED


////////////////////////////////////////////
// ON/OFF Mode Configuration
////////////////////////////////////////////

#if ANY_MODE_ON_OFF

// TCP Messages
#define TCP_OFF_DATA    0x00
#define TCP_ON_DATA     0x01
#define TCP_GET_STATE   0x03

// Boot state
#define BOOT_STATE      OFF

////////////////////////////////////////////
// Toggle Mode Configuration
////////////////////////////////////////////

#elif MODE == MODE_TOGGLE
#define TCP_TOGGLE_DATA 0x01
#define BOOT_STATE      1 // 0: OFF, 1: ON

////////////////////////////////////////////
// Pulse Mode Configuration
////////////////////////////////////////////

#elif MODE == MODE_PULSE_LOW || MODE == MODE_PULSE_HIGH
#define TCP_PULSE_DATA  0x01
#define PULSE_TIME      250 // ms

#else
#error "No mode selected"
#endif

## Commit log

2024-08-23 ESP8266: Hopefully fixed device freezing up
    [main.cpp]
2024-08-23 Schematic: Improved layout
    [Schematic.kicad_pcb, Schematic.kicad_sch]
2024-08-28 Firmware: Dropped pico w support in favor of ESP8266
2024-08-28 Modified Schematic: Minor change
    [Schematic.kicad_sch]
2024-09-03 README: Added text
    [Schematic.kicad_sch]
2024-09-04 README: Where did the schematic go!
2024-09-05 README: Updated + Schematic: Minor correction
    [Schematic.kicad_sch]
2025-05-17 Fix wrong optocoupler wiring
    [Schematic.kicad_sch]

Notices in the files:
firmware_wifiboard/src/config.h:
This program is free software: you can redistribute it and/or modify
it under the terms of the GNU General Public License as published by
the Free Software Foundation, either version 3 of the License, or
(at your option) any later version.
